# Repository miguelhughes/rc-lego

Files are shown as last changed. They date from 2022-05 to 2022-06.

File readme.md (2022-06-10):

# RC lego
DIY project for building remote controlled lego cars and adding power functions to lego, using Arduino, 3d printer and cheap available electronic components

Here you'll find code, 3d models & parts list for getting started with you own version of this, and/or mix & match to get the best for your requirements. Contributions are welcome and encouraged!

The motors & servos are controlled with PS3 controller, and can be also easily modified to work with a PS4 (Although I haven't tried yet)

# Why?

My kid was always bugging me to get him a Remote Controlled car for his birthday. As much as I understood his feeling, I didn't want to get him something that would end up in a landfill in 1-2 years, and would add nothing to his development and creativity. So I decided to make him a power Lego kit with arduino and 3d printed parts, so that he can build his own RC car and other stuff as well!
This kit is easily fixed and upgraded, and can be an entryway to programming and electronics for your kids as well

# Videos & Photos:
[Here's a version of a tank mode car](https://youtu.be/UGNO0eF9Yjw), that drives very much like a bob cat. Very easy to build and fun to drive.

With some lego technic, I was also able to build a [car with steering](https://youtu.be/Ge-JHIiQ8DI). Not the prettiest, but still fun!

complete photo & video collection:
https://photos.app.goo.gl/P4w6zJVzxgqLykxx8

# Parts list:
## Required: 

- Play Station Controller (PS3 recommended, others not tested) 
- Arduino Uno
- Arduino motor shield
- Arduino USB shield
- Bluetooth USB Dongle

## Recommended
- 2x 18650 Li-ion batteries *
- 18650 battery holder *
- Up to 4 TT Gearbox Dc motors https://www.adafruit.com/product/3777

*I tried using 4x 1.2v rechargable AA batteries, and I didn't like the result. On their own they could move a couple of the motors, but through the arduino shield they would barely move. I didn't try a 9v battery, I've seen a couple of projects using that so it might work. If you do try that route, let me know! The motor shield would handle the different voltages without issues.

## Optional
- 2 SG90 micro servos

## 3d parts

see 3d models/readme.md

# Control
Right hat's Y axis controls motor 4, X controls Servo 2. Likewise, Left hat Y controls motor 3 and X axis servo 1. 
arrows up & down will control motor 1 and left & right motor 2. 
So to use tank mode, you must plug the two right motors to motor 4 terminal, and the two left motors to motor 3 terminal. Why not one motor to each terminal, you might wonder? Because there's a conflict between the motor shield and the usb shield, and sadly motor 1 has no "speed" control, it always goes full speed.

To help wiring here I build 4 2-to-1 female to male jumper wires. (TODO: Add pictures)

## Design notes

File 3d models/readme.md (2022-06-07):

This folder is mostly a collection of 3d models I gathered from thingiverse and output of customizations I printed for customizable files.

For some of these, if you'll be printing, you'll most likely need to go to the original files & trial & error to get the sizes right.

Regarding the tt motor wrapper, there's two versions. One is more compatible with traditional lego (tt motor wrapper), and the other one is more lego technic oriented

regarding arduino-lego-mount. it needs updating, there's a hole to feed in the power input terminal, and I made a mistake in measurements so it doesn't match.

I highly recommend the [Pela Blocks](https://github.com/paulirotta/PELA-blocks) library. I was amazed at it's completeness and usefullness, as in 3d printing for lego you always get a mismatch, and parts never quite fit exactly. This amazing library has tools to adjust for your printer's standard error and then use those parameters throughout the entire library. Just brilliant. 
And there's an enormous library of parametric lego parts (pegs, blocks, different cases...), all of them customizable.

Part list: 
- arduino-lego-cover - x1 height.stl (generated from pela blocks library)
- arduino-lego-cover knobs.stl (generated from pela blocks library)
- arduino-lego-mount.stl (generated from pela blocks library)
- battery sub panel.stl (generated from pela blocks library)
- [lego wrapper for TT Motor](https://www.thingiverse.com/thing:5272973)
- [Lego Compatible DC TT Hobby Motor Mount.stl](https://www.thingiverse.com/thing:5140209)
- 18650 battery cap.stl & 18650 battery cap.f3d (these I designed myself, after I burnt 2 motor shields for placing the batteries the other way around.)
- LegoAxleToMotor.json (presets for LegoAxleToMotor.scad)
- [LegoAxleToMotor.scad](https://www.thingiverse.com/thing:1013155/files)
- Servo to Lego Axle Adapter.stl (from LegoAxleToMotor.scad, preset "servo 9g v1") After printing, heat it up and squeeze it into the servo's cog, so it takes its shape.
- TT motor to Lego Axle Adapter.stl (from LegoAxleToMotor.scad, preset "tt motor - large ones")

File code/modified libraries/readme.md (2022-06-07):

these are changes to external libraries. copy of the modified files, which should of course go into the arduino library itself.
this is a hack, but I don't know how to properly do it, specially considering arduino. I could do a fork and pull request...
You should get the original libraries, and then overwrite the corresponding files from the files in this folder. 

If you know of a better way of doing this, please let me know and/or create a PR yourself, I'd greatly appreciate that!

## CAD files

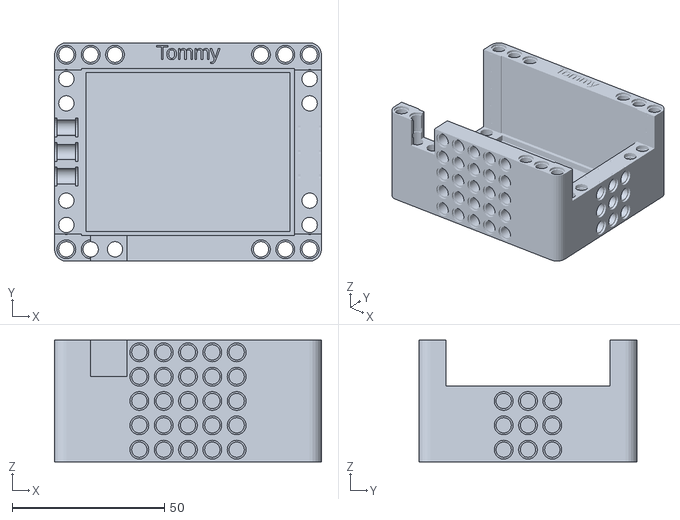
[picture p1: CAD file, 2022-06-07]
3d models/arduino-lego-mount.stl
87.8 x 71.8 x 40.0

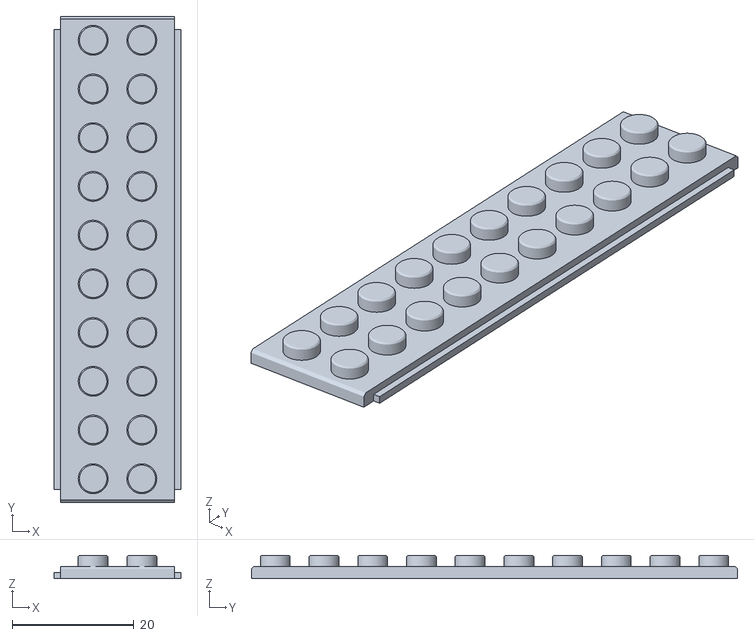
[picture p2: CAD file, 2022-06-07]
3d models/lego wrapper for TT Motor/TTMotorLegoLeft.stl
20.8 x 79.8 x 3.80

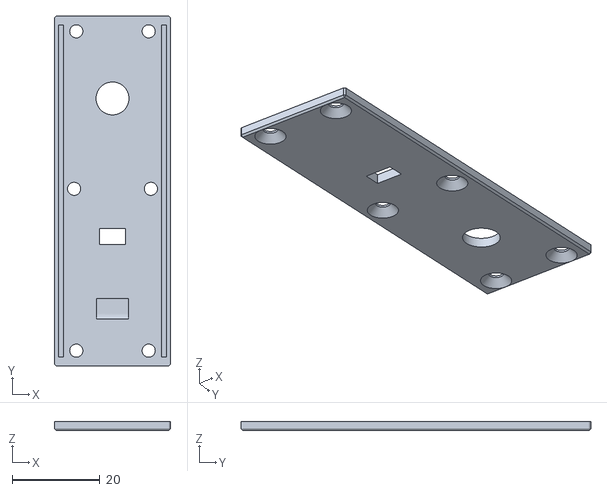
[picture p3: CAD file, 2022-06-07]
3d models/lego wrapper for TT Motor/TTMotorLegoTop.stl
26.5 x 79.8 x 2.00

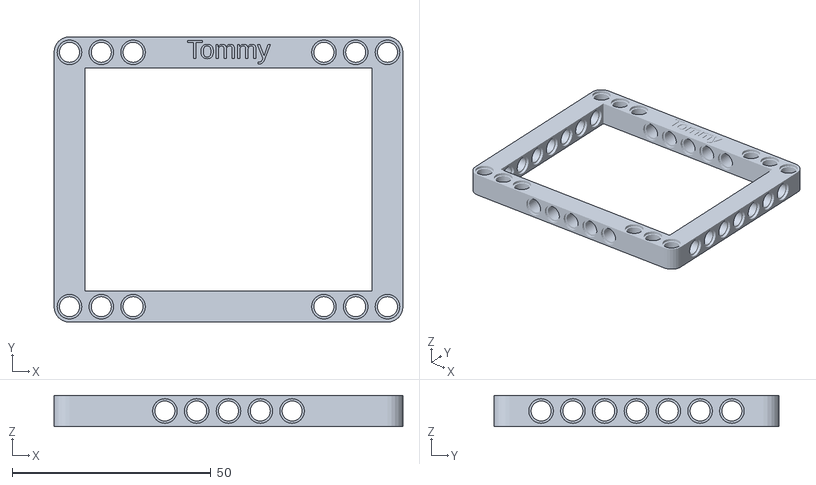
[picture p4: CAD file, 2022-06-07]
3d models/arduino-lego-cover - x1 height.stl
87.8 x 71.8 x 7.80

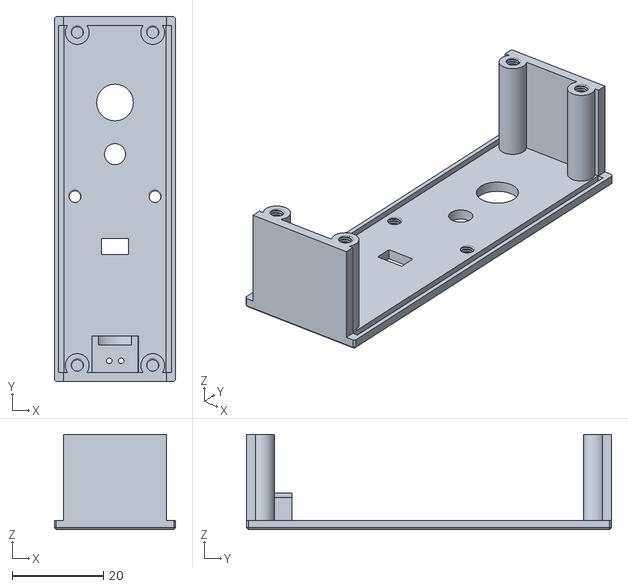
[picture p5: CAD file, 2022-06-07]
3d models/lego wrapper for TT Motor/TTMotorLegoBottom.stl
26.5 x 79.8 x 20.8

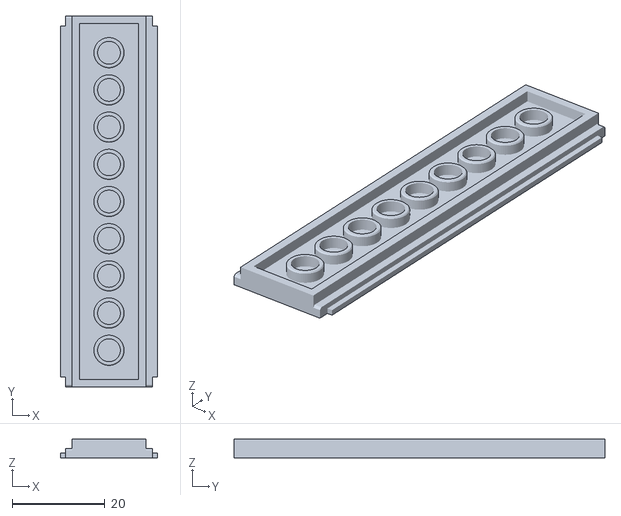
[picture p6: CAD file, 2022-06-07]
3d models/lego wrapper for TT Motor/TTMotorLegoRight.stl
20.8 x 79.8 x 4.00

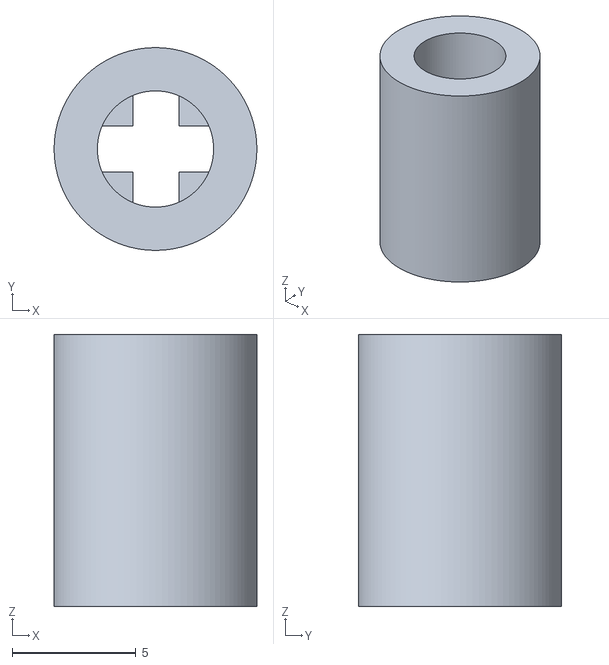
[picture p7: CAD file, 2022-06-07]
3d models/Servo to Lego Axle Adapter.stl
8.20 x 8.20 x 11.0

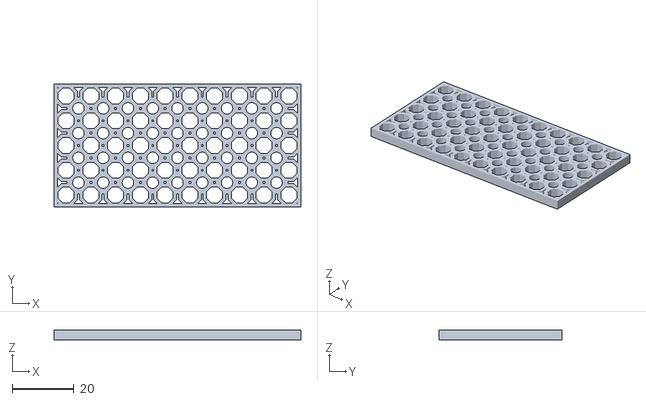
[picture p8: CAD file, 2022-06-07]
3d models/battery sub panel.stl
79.8 x 39.8 x 3.20

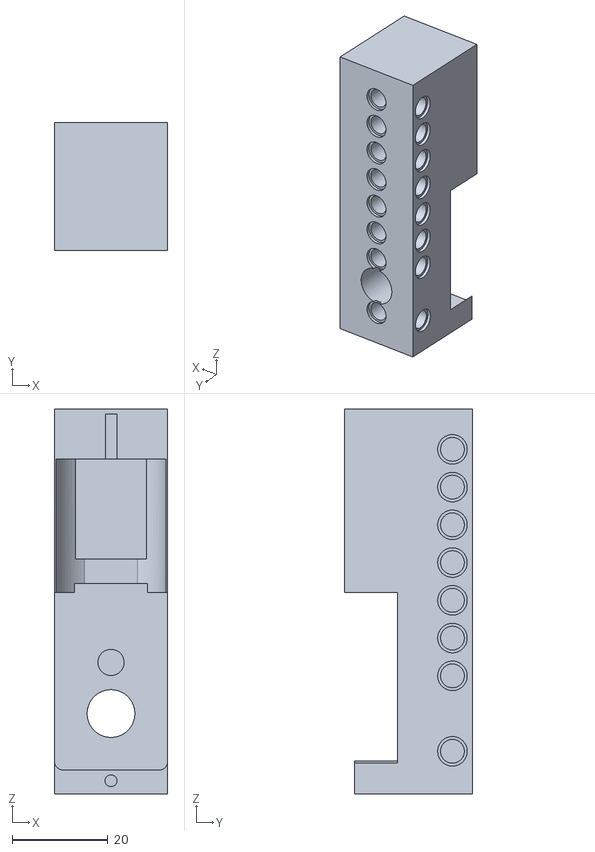
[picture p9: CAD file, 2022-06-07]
3d models/Lego Compatible DC TT Hobby Motor Mount.stl
23.7 x 26.7 x 80.6

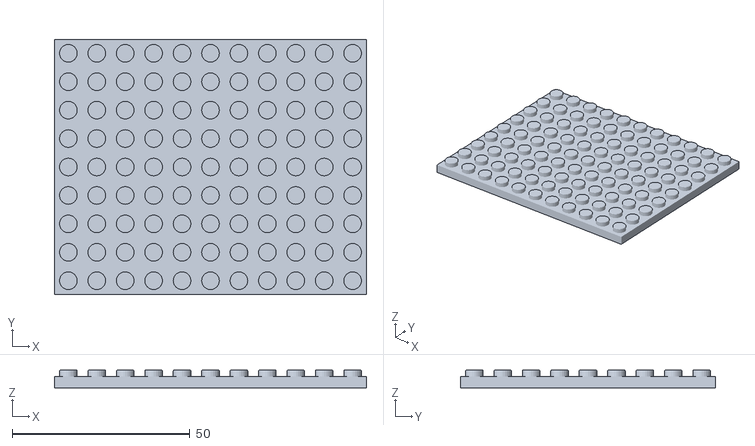
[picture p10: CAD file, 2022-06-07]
3d models/arduino-lego-cover knobs.stl
87.8 x 71.8 x 5.00

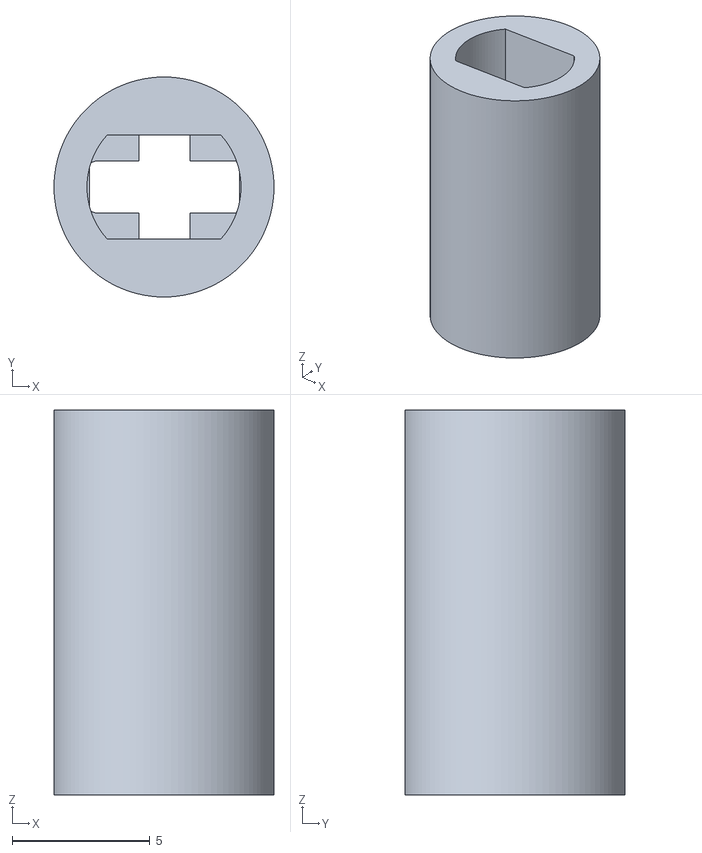
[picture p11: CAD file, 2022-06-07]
3d models/TT motor to Lego Axle Adapter.stl
8.00 x 8.00 x 14.0

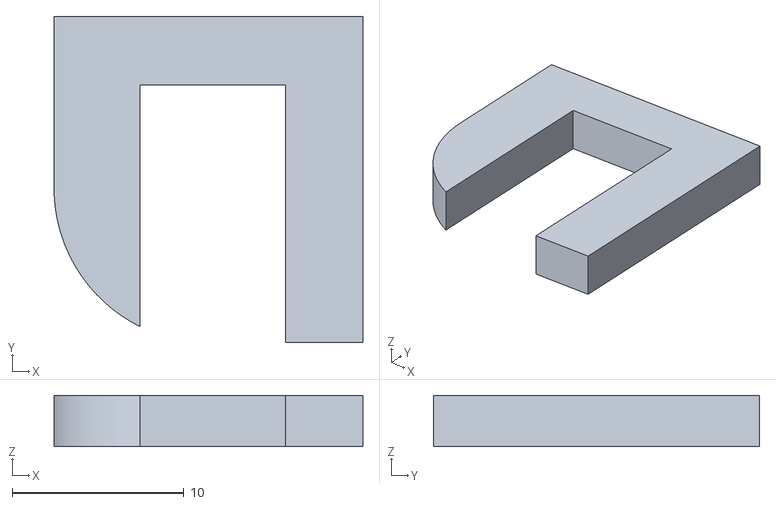
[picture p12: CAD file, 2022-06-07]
3d models/18650 battery cap.stl
18.0 x 19.0 x 3.00

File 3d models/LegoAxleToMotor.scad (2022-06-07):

// DC motor shaft to lego coupler
//
// Created by Moby Disk, 2015/02/08
// Thanks to mrob27 for thing 40410
// Changed by Drato to fit a Solarbotics GM8 Motor http://www.thingiverse.com/thing:1013155

// Diameters of various motor shafts:
// - Radio Shack 2730223: 2.0mm
// - Radio Shack 2730256: 2.3mm

// When 3D printing couplers, always try 0.1 - 0.3mm too big and test to see what actually fits

// Diameter of motor axle cutout, in mm, if motor axle is round without cutouts diameter is the same as motor_axle_diameter
motor_axle_cutout_diameter = 4.8;

// Diameter of motor axle, in mm
motor_axle_diameter = 7.1;

// Do you want to try some different axle sizes to see what fits best?
try_bigger_sizes = "no"; // [yes,no]

// Length of the axle part, in mm
axle_length = 7;
// Length of the motor axle part, in mm
motor_axle_length = 4;

// Outside radius of the coupler, in mm
coupler_outside_diameter = 9.2;

coupler_round_to_lego_axle(motor_axle_diameter,0, axle_length, motor_axle_length, coupler_outside_diameter);

spacing=coupler_outside_diameter*1.5;

if (try_bigger_sizes=="yes")
{
	for (bigger=[1:3])
	{
		translate([bigger*spacing,0,0])
		coupler_round_to_lego_axle(motor_axle_diameter,0.1*bigger, axle_length, motor_axle_length, coupler_outside_diameter);
	}
}

// Coupler for round DC motor shafts
// 
// diameter: diameter of the motor's axle
// fudge: Additional radius for the axle hole
//        - For 3D printing, the hole for the motor shaft must be larger than the actual axle itself
//        - 0.2mm and 0.3mm seem to work, but this may vary based on the printer and material
// length: A lego coupler is typically 15.9mm
// outside: outside diameter, increase for more strength
//
module coupler_round_to_lego_axle(diameter, fudge=0.2, axle_length=7, motor_axle_length=4, outside=7.2)
{
   // axle thickness is actually about 1.8 mm.  But for 3D printing, holes need to be bigger.
//   axle_gap = 1.9;
//   hole_radius = 2.65;
    axle_gap = 2;
	hole_radius = 2.75;
    
length = axle_length + motor_axle_length;
    
   motor_axle_diameter=diameter + fudge;
   difference()
   {
      // The coupler body
      translate([0,0,length/2])
      cylinder(r=outside/2,h=length,center=true,$fn=100);

      // The lego cross-axle hole
      translate([0 - hole_radius, 0 - axle_gap/2, -0.01])
      roundedRect([hole_radius * 2, axle_gap, axle_length+0.02], .2);
      translate([0 - axle_gap/2, 0 - hole_radius, -0.01])
      roundedRect([axle_gap, hole_radius * 2, axle_length+0.02], .2);

      difference()
      {
        // The hole for the motor shaft
        translate([0, 0, length-motor_axle_length/2+0.01])
        cylinder(r=motor_axle_diameter/2,h=motor_axle_length+0.01,center=true,$fn=100);
          
        translate([0,motor_axle_diameter/2+motor_axle_cutout_diameter/2, length-motor_axle_length/2+0.01])
        cube([motor_axle_diameter, motor_axle_diameter, motor_axle_length+0.01], true);
          
        translate([0,-motor_axle_diameter/2-motor_axle_cutout_diameter/2, length-motor_axle_length/2+0.01])
        cube([motor_axle_diameter, motor_axle_diameter, motor_axle_length+0.01], true);
      }
   }
}

// ---------------------------------------------------------------------------------
//
// module for rounded rectangles by tlrobinson on Thingiverse in a 
// comment posted to http://www.thingiverse.com/thing:9347 on March
// 29, 2012, 3:57:46 AM EDT
//
module roundedRect(size, radius) {  
  x = size[0];  
  y = size[1];  
  z = size[2];  
 
  linear_extrude(height=z)  
  hull() {  
    translate([radius, radius, 0])  
      circle(r=radius);  
 
    translate([x - radius, radius, 0])  
      circle(r=radius);  
 
    translate([x - radius, y - radius, 0])  
      circle(r=radius);  
 
    translate([radius, y - radius, 0])  
      circle(r=radius);  
  }  
}

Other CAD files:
3d models/18650 battery cap.f3d

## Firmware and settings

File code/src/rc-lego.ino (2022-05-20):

#include <PS3BT.h>
#include <usbhub.h>

// Satisfy the IDE, which needs to see the include statment in the ino too.
#ifdef dobogusinclude
#include <spi4teensy3.h>
#endif
#include <SPI.h>

//#include <AFMotor.h>
#include <AFMotor_routed.h>
#include <Servo.h> 
//#define EXTRAINFO
USB Usb;
BTD Btd(&Usb);
//refer to ps3bt example on instructions on how to set this.
PS3BT PS3(&Btd, 0x00, 0x1B, 0x10, 0x00, 0x2A, 0xEC);

AF_DCMotor motor1(1,MOTOR12_1KHZ);
AF_DCMotor motor2(2,MOTOR12_64KHZ);

AF_DCMotor motor3(3,MOTOR34_1KHZ);
AF_DCMotor motor4(4,MOTOR34_64KHZ);

Servo servo1;
Servo servo2;

const float hatToServoRatio = (float)180 / 256; //hat is between 0 / 255, so we do simple rule of three
bool printLogs = false;
bool connected = false;

const int maxBtSilenceTolerance = 100; //after this much time, motors will be stopped - no other action
uint32_t lastPrint = 0;
long lastBtMessageTime = 0;

uint32_t resetTimer = 0;
const int resetWait = 3000;

void setup() {
  Serial.begin(115200);
#if !defined(__MIPSEL__)
  while (!Serial); // Wait for serial port to connect - used on Leonardo, Teensy and other boards with built-in USB CDC serial connection
#endif
  if (Usb.Init() == -1) {
    Serial.print(F("\r\nOSC did not start"));
    while (1); //halt
  }
  Serial.print(F("\r\nPS3 Bluetooth Library Started"));
  Btd.setErrorCallback(onBTError);

  motor1.setSpeed(255);
  motor2.setSpeed(255);
  // motor3.setSpeed(200);
  // motor4.setSpeed(200);
  servo1.attach(A0); 
  servo2.attach(A1);
}

void loop()
{
	btloop();
#ifdef EXTRAINFO
  if (millis() / 100 > lastPrint)
  {
    Serial.print("BT last msg: ");
    Serial.print(PS3.getLastMessageTime());
    Serial.println();
    lastPrint = millis()/100;
  }
  #endif
}

void btloop()
{
  Usb.Task();

  if (PS3.PS3Connected)
  {
    if (!connected)
    {
      connectionDetected();
      connected = true;
    }

    updateServo(LeftHatX, servo1);
    updateServo(RightHatX, servo2);

    updateMotorFromHat(LeftHatY, motor3);
    updateMotorFromHat(RightHatY, motor4);
    updateMotorFromButtons(UP, DOWN, motor1);
    updateMotorFromButtons(LEFT, RIGHT, motor2);
    
    if (PS3.getButtonClick(CROSS))
    {
      printLogs = !printLogs;
      if (printLogs)
        Serial.println("logs enabled");
      else
        Serial.println("logs disabled");
    }
    if (printLogs)
    {
      printButtonsAndHats();
    }
    idleBtCheck();
  }
  else
  {
    if (connected)
    {
      disconnectionDetected();
      
      connected = false;
    }
    stopAllMotors(); //just in case, sometimes after a disconnect or failed connection a motor start is fired and they continue running
  }
}

void idleBtCheck()
{
  long lastMsg = PS3.getLastMessageTime();
  if (lastMsg - lastBtMessageTime > maxBtSilenceTolerance)
  {
    Serial.println("Idle BT detected");
    stopAllMotors();
  }
  lastBtMessageTime = lastMsg;
}

void connectionDetected()
{
  Serial.println("connection Detected");
}

void disconnectionDetected()
{
  Serial.println("disconnection Detected");
}

void (*resetDevice)(void) = 0; //standard reset function - causes arduino to crash

void onBTError(String type, uint8_t code)
{
  stopAllMotors(); //stop all motors so that if it's a car it stops on the spot instead of crashing into something
  if (type != "ACL" || code != 0xF0) //acl and 0xF0 sometimes happens and it continues to work
  {
    Serial.println();
    //These weren't reliable enough, on some of the errors it freezes and it won't recover. our loop isn't called in those cases (see BT&usb errors & application behavior)
    // Serial.println("forcing disconnect");
    // // Btd.disconnect();
    // PS3.disconnect();
    // setResetTimer();
    Serial.println("forcing reset");
    Serial.flush(); //othw messages are truncated. This seems to help with BT reconnection after reset as well.
    resetDevice();
  }
}

void stopAllMotors()
{
  motor1.run(RELEASE);
  motor2.run(RELEASE);
  motor3.run(RELEASE);
  motor4.run(RELEASE);
}

bool isHatCentered(AnalogHatEnum hat)
{
  return isHatCentered(PS3.getAnalogHat(hat));
}

bool isHatCentered(uint8_t hatValue)
{
  return hatValue > 117 && hatValue < 137;
}

void updateServo(AnalogHatEnum hat, Servo servo)
{
  int angle = hatToServo(PS3.getAnalogHat(hat));
  servo.write(angle);
}

int hatToServo(uint8_t hatValue)
{
  int angle = hatValue * hatToServoRatio;
  // Serial.print("hat value ");
  // Serial.print(hatValue);
  // Serial.print(" to servo is angle ");
  // Serial.println(angle);
  return angle;
}

void updateMotorFromHat(AnalogHatEnum hat, AF_DCMotor motor)
{
  uint8_t hatValue = PS3.getAnalogHat(hat);
  uint8_t direction;
  uint8_t speed;
  hatToMotor(hatValue, &speed, &direction);

  motor.setSpeed(speed);
  motor.run(direction);
}

void updateMotorFromButtons(ButtonEnum firstButton, ButtonEnum secondButton, AF_DCMotor motor)
{
  bool firstButtonPressed = PS3.getButtonPress(firstButton);
  bool secondButtonPressed = PS3.getButtonPress(secondButton);
  
  if (firstButtonPressed)
  {
    motor.run(FORWARD);
  }
  else if (secondButtonPressed)
  {
    motor.run(BACKWARD);
  }
  else
  {
    motor.run(RELEASE);
  }
}

void hatToMotor(uint8_t hatValue, uint8_t *speed, uint8_t *direction)
{
  //hat value goes from 0 to 255. speed does as well, so we mutiply by 2, subtract half and then use positive/negative to figure out direction.
  int converted = hatValue * 2 - 255;

  if (!isHatCentered(hatValue))
  {
    if (converted > 0)
      *direction = FORWARD;
    else
      *direction = BACKWARD;
  }
  else
    *direction = RELEASE;

  *speed = abs(converted);
}

void printButtonsAndHats()
{
  if (PS3.getAnalogHat(LeftHatX) > 137 || PS3.getAnalogHat(LeftHatX) < 117 || PS3.getAnalogHat(LeftHatY) > 137 || PS3.getAnalogHat(LeftHatY) < 117 || PS3.getAnalogHat(RightHatX) > 137 || PS3.getAnalogHat(RightHatX) < 117 || PS3.getAnalogHat(RightHatY) > 137 || PS3.getAnalogHat(RightHatY) < 117)
  {
    Serial.print(F("\r\nLeftHatX: "));
    Serial.print(PS3.getAnalogHat(LeftHatX));
    Serial.print(F("\tLeftHatY: "));
    Serial.print(PS3.getAnalogHat(LeftHatY));
    if (PS3.PS3Connected)
    { // The Navigation controller only have one joystick
      Serial.print(F("\tRightHatX: "));
      Serial.print(PS3.getAnalogHat(RightHatX));
      Serial.print(F("\tRightHatY: "));
      Serial.print(PS3.getAnalogHat(RightHatY));
    }
  }

  // Analog button values can be read from almost all buttons
  if (PS3.getAnalogButton(L2) || PS3.getAnalogButton(R2))
  {
    Serial.print(F("\r\nL2: "));
    Serial.print(PS3.getAnalogButton(L2));
    if (PS3.PS3Connected)
    {
      Serial.print(F("\tR2: "));
      Serial.print(PS3.getAnalogButton(R2));
    }
  }

  if (PS3.getButtonClick(PS))
  {
    Serial.print(F("\r\nPS"));
    PS3.disconnect();
  }
  else
  {
    if (PS3.getButtonClick(TRIANGLE))
    {
      Serial.print(F("\r\nTriangle"));
    }
    if (PS3.getButtonClick(CIRCLE))
    {
      Serial.print(F("\r\nCircle"));
      PS3.setRumbleOn(RumbleHigh);
    }
    if (PS3.getButtonClick(CROSS))
      Serial.print(F("\r\nCross"));
    if (PS3.getButtonClick(SQUARE))
      Serial.print(F("\r\nSquare"));

    if (PS3.getButtonClick(UP))
    {
      Serial.print(F("\r\nUp"));
      if (PS3.PS3Connected)
      {
        PS3.setLedOff();
        PS3.setLedOn(LED4);
      }
    }
    if (PS3.getButtonClick(RIGHT))
    {
      Serial.print(F("\r\nRight"));
      if (PS3.PS3Connected)
      {
        PS3.setLedOff();
        PS3.setLedOn(LED1);
      }
    }
    if (PS3.getButtonClick(DOWN))
    {
      Serial.print(F("\r\nDown"));
      if (PS3.PS3Connected)
      {
        PS3.setLedOff();
        PS3.setLedOn(LED2);
      }
    }
    if (PS3.getButtonClick(LEFT))
    {
      Serial.print(F("\r\nLeft"));
      if (PS3.PS3Connected)
      {
        PS3.setLedOff();
        PS3.setLedOn(LED3);
      }
    }

    if (PS3.getButtonClick(L1))
      Serial.print(F("\r\nL1"));
    if (PS3.getButtonClick(L3))
      Serial.print(F("\r\nL3"));
    if (PS3.getButtonClick(R1))
      Serial.print(F("\r\nR1"));
    if (PS3.getButtonClick(R3))
      Serial.print(F("\r\nR3"));

    if (PS3.getButtonClick(SELECT))
    {
      Serial.print(F("\r\nSelect - "));
      PS3.printStatusString();
    }
    if (PS3.getButtonClick(START))
    {
      Serial.print(F("\r\nStart"));
    }
  }
}

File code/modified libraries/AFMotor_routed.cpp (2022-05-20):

// Adafruit Motor shield library
// copyright Adafruit Industries LLC, 2009
// this code is public domain, enjoy!


#if (ARDUINO >= 100)
  #include "Arduino.h"
#else
  #if defined(__AVR__)
    #include <avr/io.h>
  #endif
  #include "WProgram.h"
#endif

#include "AFMotor_routed.h"



static uint8_t latch_state;

#if (MICROSTEPS == 8)
uint8_t microstepcurve[] = {0, 50, 98, 142, 180, 212, 236, 250, 255};
#elif (MICROSTEPS == 16)
uint8_t microstepcurve[] = {0, 25, 50, 74, 98, 120, 141, 162, 180, 197, 212, 225, 236, 244, 250, 253, 255};
#endif

AFMotorController::AFMotorController(void) {
    TimerInitalized = false;
}

void AFMotorController::enable(void) {
  // setup the latch
  /*
  LATCH_DDR |= _BV(LATCH);
  ENABLE_DDR |= _BV(ENABLE);
  CLK_DDR |= _BV(CLK);
  SER_DDR |= _BV(SER);
  */
  pinMode(MOTORLATCH, OUTPUT);
  pinMode(MOTORENABLE, OUTPUT);
  pinMode(MOTORDATA, OUTPUT);
  pinMode(MOTORCLK, OUTPUT);

  latch_state = 0;

  latch_tx();  // "reset"

  //ENABLE_PORT &= ~_BV(ENABLE); // enable the chip outputs!
  digitalWrite(MOTORENABLE, LOW);
}


void AFMotorController::latch_tx(void) {
  uint8_t i;

  //LATCH_PORT &= ~_BV(LATCH);
  digitalWrite(MOTORLATCH, LOW);

  //SER_PORT &= ~_BV(SER);
  digitalWrite(MOTORDATA, LOW);

  for (i=0; i<8; i++) {
    //CLK_PORT &= ~_BV(CLK);
    digitalWrite(MOTORCLK, LOW);

    if (latch_state & _BV(7-i)) {
      //SER_PORT |= _BV(SER);
      digitalWrite(MOTORDATA, HIGH);
    } else {
      //SER_PORT &= ~_BV(SER);
      digitalWrite(MOTORDATA, LOW);
    }
    //CLK_PORT |= _BV(CLK);
    digitalWrite(MOTORCLK, HIGH);
  }
  //LATCH_PORT |= _BV(LATCH);
  digitalWrite(MOTORLATCH, HIGH);
}

static AFMotorController MC;

/******************************************
               MOTORS
******************************************/
inline void initPWM1(uint8_t freq) {
#if defined(__AVR_ATmega8__) || \
    defined(__AVR_ATmega48__) || \
    defined(__AVR_ATmega88__) || \
    defined(__AVR_ATmega168__) || \
    defined(__AVR_ATmega328P__)
    // use PWM from timer2A on PB3 (Arduino pin #11)
    TCCR2A |= _BV(COM2A1) | _BV(WGM20) | _BV(WGM21); // fast PWM, turn on oc2a
    TCCR2B = freq & 0x7;
    OCR2A = 0;
#elif defined(__AVR_ATmega1280__) || defined(__AVR_ATmega2560__)
    // on arduino mega, pin 11 is now PB5 (OC1A)
    TCCR1A |= _BV(COM1A1) | _BV(WGM10); // fast PWM, turn on oc1a
    TCCR1B = (freq & 0x7) | _BV(WGM12);
    OCR1A = 0;
#elif defined(__PIC32MX__)
    #if defined(PIC32_USE_PIN9_FOR_M1_PWM)
        // Make sure that pin 11 is an input, since we have tied together 9 and 11
        pinMode(9, OUTPUT);
        pinMode(11, INPUT);
        if (!MC.TimerInitalized)
        {   // Set up Timer2 for 80MHz counting fro 0 to 256
            T2CON = 0x8000 | ((freq & 0x07) << 4); // ON=1, FRZ=0, SIDL=0, TGATE=0, TCKPS=<freq>, T32=0, TCS=0; // ON=1, FRZ=0, SIDL=0, TGATE=0, TCKPS=0, T32=0, TCS=0
            TMR2 = 0x0000;
            PR2 = 0x0100;
            MC.TimerInitalized = true;
        }
         // Setup OC4 (pin 9) in PWM mode, with Timer2 as timebase
        OC4CON = 0x8006;    // OC32 = 0, OCTSEL=0, OCM=6
        OC4RS = 0x0000;
        OC4R = 0x0000;
    #elif defined(PIC32_USE_PIN10_FOR_M1_PWM)
        // Make sure that pin 11 is an input, since we have tied together 9 and 11
        pinMode(10, OUTPUT);
        pinMode(11, INPUT);
        if (!MC.TimerInitalized)
        {   // Set up Timer2 for 80MHz counting fro 0 to 256
            T2CON = 0x8000 | ((freq & 0x07) << 4); // ON=1, FRZ=0, SIDL=0, TGATE=0, TCKPS=<freq>, T32=0, TCS=0; // ON=1, FRZ=0, SIDL=0, TGATE=0, TCKPS=0, T32=0, TCS=0
            TMR2 = 0x0000;
            PR2 = 0x0100;
            MC.TimerInitalized = true;
        }
         // Setup OC5 (pin 10) in PWM mode, with Timer2 as timebase
        OC5CON = 0x8006;    // OC32 = 0, OCTSEL=0, OCM=6
        OC5RS = 0x0000;
        OC5R = 0x0000;
    #else
        // If we are not using PWM for pin 11, then just do digital
        digitalWrite(11, LOW);
    #endif
#else
   #error "This chip is not supported!"
#endif
    #if !defined(PIC32_USE_PIN9_FOR_M1_PWM) && !defined(PIC32_USE_PIN10_FOR_M1_PWM)
        pinMode(11, OUTPUT);
    #endif
}

inline void setPWM1(uint8_t s) {
#if defined(__AVR_ATmega8__) || \
    defined(__AVR_ATmega48__) || \
    defined(__AVR_ATmega88__) || \
    defined(__AVR_ATmega168__) || \
    defined(__AVR_ATmega328P__)
    // use PWM from timer2A on PB3 (Arduino pin #11)
    OCR2A = s;
#elif defined(__AVR_ATmega1280__) || defined(__AVR_ATmega2560__)
    // on arduino mega, pin 11 is now PB5 (OC1A)
    OCR1A = s;
#elif defined(__PIC32MX__)
    #if defined(PIC32_USE_PIN9_FOR_M1_PWM)
        // Set the OC4 (pin 9) PMW duty cycle from 0 to 255
        OC4RS = s;
    #elif defined(PIC32_USE_PIN10_FOR_M1_PWM)
        // Set the OC5 (pin 10) PMW duty cycle from 0 to 255
        OC5RS = s;
    #else
        // If we are not doing PWM output for M1, then just use on/off
        if (s > 127)
        {
            digitalWrite(11, HIGH);
        }
        else
        {
            digitalWrite(11, LOW);
        }
    #endif
#else
   #error "This chip is not supported!"
#endif
}

inline void initPWM2(uint8_t freq) {
#if defined(__AVR_ATmega8__) || \
    defined(__AVR_ATmega48__) || \
    defined(__AVR_ATmega88__) || \
    defined(__AVR_ATmega168__) || \
    defined(__AVR_ATmega328P__)
    // use PWM from timer2B (pin 3)
    TCCR2A |= _BV(COM2B1) | _BV(WGM20) | _BV(WGM21); // fast PWM, turn on oc2b
    TCCR2B = freq & 0x7;
    OCR2B = 0;
#elif defined(__AVR_ATmega1280__) || defined(__AVR_ATmega2560__)
    // on arduino mega, pin 3 is now PE5 (OC3C)
    TCCR3A |= _BV(COM1C1) | _BV(WGM10); // fast PWM, turn on oc3c
    TCCR3B = (freq & 0x7) | _BV(WGM12);
    OCR3C = 0;
#elif defined(__PIC32MX__)
    if (!MC.TimerInitalized)
    {   // Set up Timer2 for 80MHz counting fro 0 to 256
        T2CON = 0x8000 | ((freq & 0x07) << 4); // ON=1, FRZ=0, SIDL=0, TGATE=0, TCKPS=<freq>, T32=0, TCS=0; // ON=1, FRZ=0, SIDL=0, TGATE=0, TCKPS=0, T32=0, TCS=0
        TMR2 = 0x0000;
        PR2 = 0x0100;
        MC.TimerInitalized = true;
    }
    // Setup OC1 (pin3) in PWM mode, with Timer2 as timebase
    OC1CON = 0x8006;    // OC32 = 0, OCTSEL=0, OCM=6
    OC1RS = 0x0000;
    OC1R = 0x0000;
#else
   #error "This chip is not supported!"
#endif

    pinMode(3, OUTPUT);
}

inline void setPWM2(uint8_t s) {
#if defined(__AVR_ATmega8__) || \
    defined(__AVR_ATmega48__) || \
    defined(__AVR_ATmega88__) || \
    defined(__AVR_ATmega168__) || \
    defined(__AVR_ATmega328P__)
    // use PWM from timer2A on PB3 (Arduino pin #11)
    OCR2B = s;
#elif defined(__AVR_ATmega1280__) || defined(__AVR_ATmega2560__)
    // on arduino mega, pin 11 is now PB5 (OC1A)
    OCR3C = s;
#elif defined(__PIC32MX__)
    // Set the OC1 (pin3) PMW duty cycle from 0 to 255
    OC1RS = s;
#else
   #error "This chip is not supported!"
#endif
}
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

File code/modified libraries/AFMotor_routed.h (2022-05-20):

// Adafruit Motor shield library
// copyright Adafruit Industries LLC, 2009
// this code is public domain, enjoy!
/*
modifications by MH
pin 9 -> A0
pin 10 -> A1
pin 11 -> A2
pin 12 -> A3

 */
/*
 * Usage Notes:
 * For PIC32, all features work properly with the following two exceptions:
 *
 * 1) Because the PIC32 only has 5 PWM outputs, and the AFMotor shield needs 6
 *    to completely operate (four for motor outputs and two for RC servos), the
 *    M1 motor output will not have PWM ability when used with a PIC32 board.
 *    However, there is a very simple workaround. If you need to drive a stepper
 *    or DC motor with PWM on motor output M1, you can use the PWM output on pin
 *    9 or pin 10 (normally use for RC servo outputs on Arduino, not needed for 
 *    RC servo outputs on PIC32) to drive the PWM input for M1 by simply putting
 *    a jumber from pin 9 to pin 11 or pin 10 to pin 11. Then uncomment one of the
 *    two #defines below to activate the PWM on either pin 9 or pin 10. You will
 *    then have a fully functional microstepping for 2 stepper motors, or four
 *    DC motor outputs with PWM.
 *
 * 2) There is a conflict between RC Servo outputs on pins 9 and pins 10 and 
 *    the operation of DC motors and stepper motors as of 9/2012. This issue
 *    will get fixed in future MPIDE releases, but at the present time it means
 *    that the Motor Party example will NOT work properly. Any time you attach
 *    an RC servo to pins 9 or pins 10, ALL PWM outputs on the whole board will
 *    stop working. Thus no steppers or DC motors.
 * 
 */
// <BPS> 09/15/2012 Modified for use with chipKIT boards


#ifndef _AFMotor_h_
#define _AFMotor_h_

#include <inttypes.h>
#if defined(__AVR__)
    #include <avr/io.h>

    //#define MOTORDEBUG 1

    #define MICROSTEPS 16                       // 8 or 16

    #define MOTOR12_64KHZ _BV(CS20)             // no prescale
    #define MOTOR12_8KHZ _BV(CS21)              // divide by 8
    #define MOTOR12_2KHZ _BV(CS21) | _BV(CS20)  // divide by 32
    #define MOTOR12_1KHZ _BV(CS22)              // divide by 64

    #define MOTOR34_64KHZ _BV(CS00)             // no prescale
    #define MOTOR34_8KHZ _BV(CS01)              // divide by 8
    #define MOTOR34_1KHZ _BV(CS01) | _BV(CS00)  // divide by 64
    
    #define DC_MOTOR_PWM_RATE   MOTOR34_8KHZ    // PWM rate for DC motors
    #define STEPPER1_PWM_RATE   MOTOR12_64KHZ   // PWM rate for stepper 1
    #define STEPPER2_PWM_RATE   MOTOR34_64KHZ   // PWM rate for stepper 2
    
#elif defined(__PIC32MX__)
    //#define MOTORDEBUG 1
    
    // Uncomment the one of following lines if you have put a jumper from 
    // either pin 9 to pin 11 or pin 10 to pin 11 on your Motor Shield.
    // Either will enable PWM for M1
    //#define PIC32_USE_PIN9_FOR_M1_PWM
    //#define PIC32_USE_PIN10_FOR_M1_PWM

    #define MICROSTEPS 16       // 8 or 16

    // For PIC32 Timers, define prescale settings by PWM frequency
    #define MOTOR12_312KHZ  0   // 1:1, actual frequency 312KHz
    #define MOTOR12_156KHZ  1   // 1:2, actual frequency 156KHz
    #define MOTOR12_64KHZ   2   // 1:4, actual frequency 78KHz
    #define MOTOR12_39KHZ   3   // 1:8, acutal frequency 39KHz
    #define MOTOR12_19KHZ   4   // 1:16, actual frequency 19KHz
    #define MOTOR12_8KHZ    5   // 1:32, actual frequency 9.7KHz
    #define MOTOR12_4_8KHZ  6   // 1:64, actual frequency 4.8KHz
    #define MOTOR12_2KHZ    7   // 1:256, actual frequency 1.2KHz
    #define MOTOR12_1KHZ    7   // 1:256, actual frequency 1.2KHz

    #define MOTOR34_312KHZ  0   // 1:1, actual frequency 312KHz
    #define MOTOR34_156KHZ  1   // 1:2, actual frequency 156KHz
    #define MOTOR34_64KHZ   2   // 1:4, actual frequency 78KHz
    #define MOTOR34_39KHZ   3   // 1:8, acutal frequency 39KHz
    #define MOTOR34_19KHZ   4   // 1:16, actual frequency 19KHz
    #define MOTOR34_8KHZ    5   // 1:32, actual frequency 9.7KHz
    #define MOTOR34_4_8KHZ  6   // 1:64, actual frequency 4.8KHz
    #define MOTOR34_2KHZ    7   // 1:256, actual frequency 1.2KHz
    #define MOTOR34_1KHZ    7   // 1:256, actual frequency 1.2KHz
    
    // PWM rate for DC motors.
    #define DC_MOTOR_PWM_RATE   MOTOR34_39KHZ
    // Note: for PIC32, both of these must be set to the same value
    // since there's only one timebase for all 4 PWM outputs
    #define STEPPER1_PWM_RATE   MOTOR12_39KHZ
    #define STEPPER2_PWM_RATE   MOTOR34_39KHZ
    
#endif

// Bit positions in the 74HCT595 shift register output
#define MOTOR1_A 2
#define MOTOR1_B 3
#define MOTOR2_A 1
#define MOTOR2_B 4
#define MOTOR4_A 0
#define MOTOR4_B 6
#define MOTOR3_A 5
#define MOTOR3_B 7

// Constants that the user passes in to the motor calls
#define FORWARD 1
#define BACKWARD 2
#define BRAKE 3
#define RELEASE 4

// Constants that the user passes in to the stepper calls
#define SINGLE 1
#define DOUBLE 2
#define INTERLEAVE 3
#define MICROSTEP 4

/*
#define LATCH 4
#define LATCH_DDR DDRB
#define LATCH_PORT PORTB

#define CLK_PORT PORTD
#define CLK_DDR DDRD
#define CLK 4

#define ENABLE_PORT PORTD
#define ENABLE_DDR DDRD
#define ENABLE 7

#define SER 0
#define SER_DDR DDRB
#define SER_PORT PORTB
*/

// Arduino pin names for interface to 74HCT595 latch
#define MOTORLATCH A3
#define MOTORCLK 4
#define MOTORENABLE 7
#define MOTORDATA 8

class AFMotorController
{
  public:
    AFMotorController(void);
    void enable(void);
    friend class AF_DCMotor;
    void latch_tx(void);
    uint8_t TimerInitalized;
};

class AF_DCMotor
{
 public:
  AF_DCMotor(uint8_t motornum, uint8_t freq = DC_MOTOR_PWM_RATE);
  void run(uint8_t);
  void setSpeed(uint8_t);

 private:
  uint8_t motornum, pwmfreq;
};

class AF_Stepper {
 public:
  AF_Stepper(uint16_t, uint8_t);
  void step(uint16_t steps, uint8_t dir,  uint8_t style = SINGLE);
  void setSpeed(uint16_t);
  uint8_t onestep(uint8_t dir, uint8_t style);
  void release(void);
  uint16_t revsteps; // # steps per revolution
  uint8_t steppernum;
  uint32_t usperstep, steppingcounter;
 private:
  uint8_t currentstep;

};

uint8_t getlatchstate(void);

#endif

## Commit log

2022-05-06 4 motors working, 2 with hats, 2 with direction buttons
2022-05-06 4 motors and 2 servos working
2022-05-06 add turning logs on/off via Cross button
2022-05-06 fix glitch in motor by control by hat
    [rc-lego.ino]
2022-05-20 work in progress. troubleshoot & recover from bt connection issues.
    [rc-lego.ino]
2022-05-20 decent working solution. on error it just restarts & there's also the idle check to stop motors. One must press pair twice on the control, but the light on the dongle gives enough info.
    [rc-lego.ino]
2022-05-20 BT error/recovery ok. Stops on problems and it's easy enough to reconnect after reset.
    [rc-lego.ino]
2022-05-20 re-enable buttons log & add option to turn on/off bt last message
2022-06-07 Add printed 3d models
    [DC_Motor_Adapter_to_lego_v2.stl, LegoAxleToMotor.json, LegoAxleToMotor.scad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]
2022-06-07 Add 3d parts readme rename models to match original thingiverse projects more info on main readme. Also more info on modified libraries readme
    [18650 battery cap.f3d, 18650 battery cap.stl, Lego Compatible DC TT Hobby Motor Mount.stl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]
